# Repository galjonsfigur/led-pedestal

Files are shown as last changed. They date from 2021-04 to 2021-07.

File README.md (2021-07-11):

# LED Pedestal

This repository contains hardware, firmware and
3D-printable case for the LED Pedestal project.

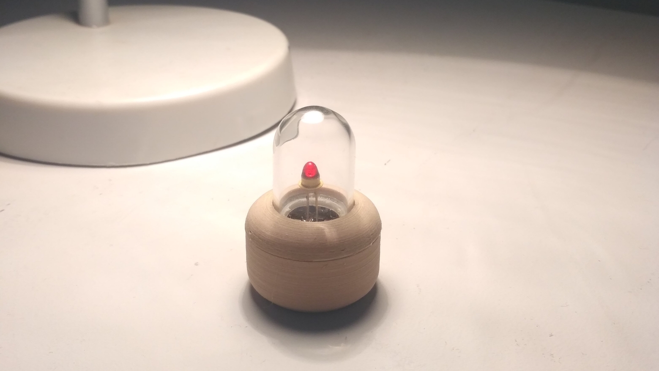
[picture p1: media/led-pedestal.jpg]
LED Pedestal


## What is this project?

The name says it all - it's just a fancy-looking circuit
that can blink your precious (retro or not) LED that you probably
still keep at the bottom of your component drawer. The circuit is heavily
over-complicated and the same thing could be done using 3 or 4 components total,
but it looks cool and has some nice features:

- PIC10F222 micro controller with sophisticated firmware (as far as 512 bytes 
firmware written in C with some assembly can be)
- Whole 3 (three!) randomly-parameterized LED effects to select from 
- Micro USB for charging the Li-Ion battery with all the (unnecessary)
protection circuits (overcharge, over-discharge and short-circuit protection) 
- small button for checking battery level and changing LED Blinking modes
- reaction to connecting charger and showing charging status
- can work while charging from USB

And on top of that, cool-looking glass dome case 
to encapsulate the spirit of your LED!

LED Pedestal

## How do I make my own?

Before you start you have to:

- be able to solder small SMD components (TSSOP-8 is the smallest-pitch used in
the design) and use hot-air or hot plate (or frying pan) to solder
micro USB port (you could try to use soldering iron but it will be much more 
tedious) 
- be able to program PIC10F222 micro controller (even cheap PICKit2 can be used)
- calculate current-limiting resistor for your LED assuming 3.3V drive voltage,
voltage drop and recommended current from LED datasheet. You can calculate it
using the following formula: `R = (V_battery - V_LEDdrop) / I_LED` or just slam
68 Ohm one and call it a day 

You can use available [gerber zip](hardware/gerbers_v2.zip) archive and order
the PCB from your favorite (or the cheapest) PCB manufacturer and buy the 
necessary components listed in the Bill of materials (most of them should be
cheap and easy to obtain even from places like AliExpress).

Bill of materials can be found [here.](bom.txt)

#### Assembly of the PCB

If you are soldering the PCB by hand, begin with USB port and the button 
Jumper from middle pad to pad marked with an arrow is variant with Random 
Seed Generator (Not implemented) and the jumper from middle pad to the 
third one (the one without arrow mark) is variant with battery 
measurement - connected by default in revision 2 of PCB, so if by any chance
you uploaded `gerbers_v1` instead of `gerbers_v2` you will have to solder it.
If your precious LED still has long legs don't cut them and instead solder it to
be as high above the PCB as possible! Cathode is the square pad. After soldering
SMD components solder trough-hole JST socket or the Li-ion cell directly.

If for whatever reason don't want to use 
[SOICBite](https://github.com/SimonMerrett/SOICbite) you can solder wires to the
pads directly and connect it to the programmer or program the PIC before
soldering it. Connection diagram can be found in the schematic and programming 
pads description in `media` folder). Example programming jig:

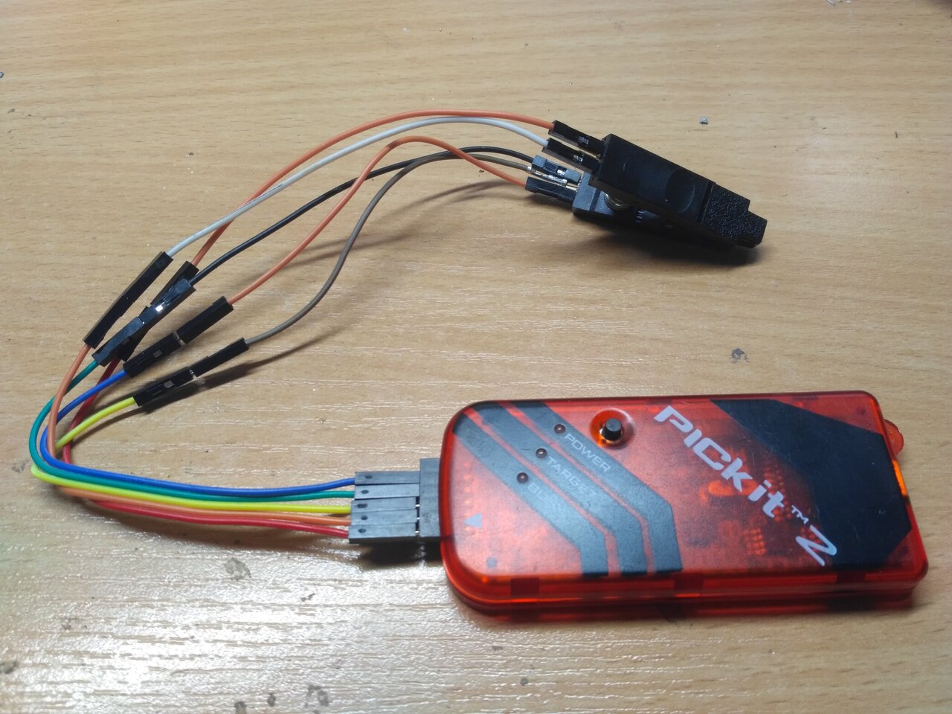
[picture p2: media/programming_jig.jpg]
Programming Jig


After connecting the Li-Ion cell you have to connect it to the USB
to start the protection circuits (they go to fail-save mode if the battery was
disconnected) and you should have a nice and working pedestal!

#### Assembling the case

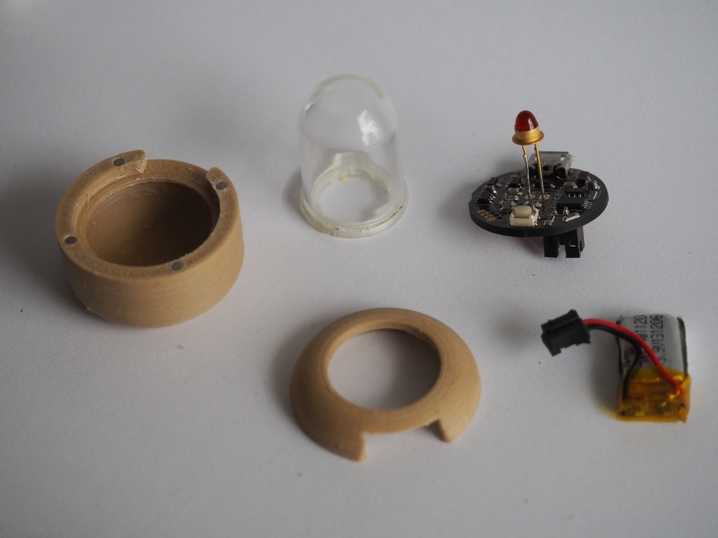
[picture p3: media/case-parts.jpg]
Case parts


To assemble the case you will need following elements:

- three 3D-printed parts - STL files are in `case` folder. I recommend to print
them with some nice material and fine settings - they should look better than
your average print!
- eight round 2x2mm N35 magnets
- 12x18mm glass dome

You should be able to get those on AliExpress or similar sites. 
Glue 3D-printed ring to the bottom of glass dome and put the magnets
into the holes in such configuration that two case parts attract each 
other. then put the PCB and the battery into the bottom part, the glass dome
into the upper one and they should snap together. 

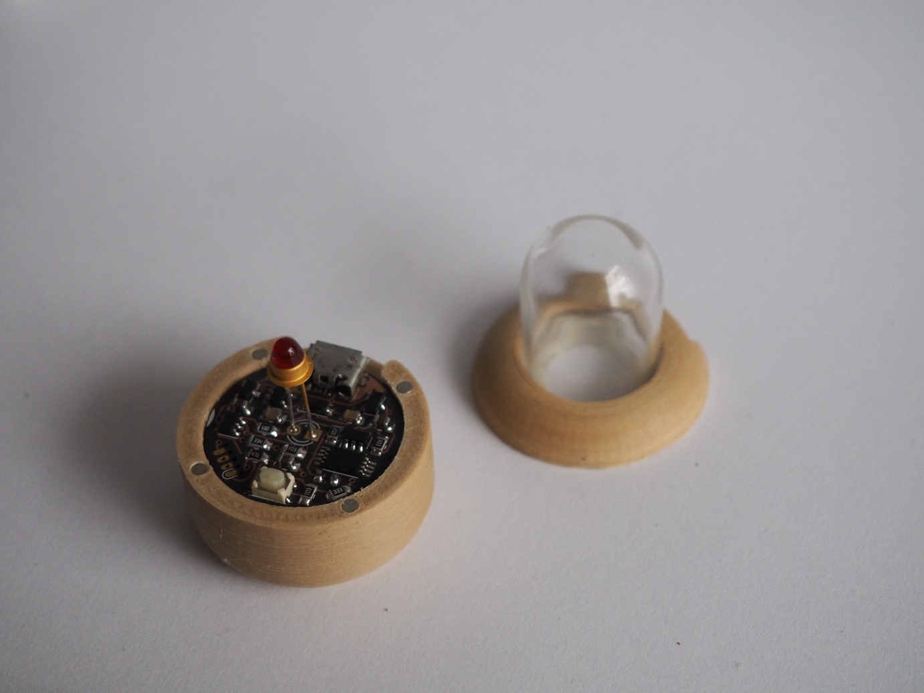
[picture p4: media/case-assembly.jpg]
Case


## Battery life
On 35mAh Li-ion 3.7V battery it should work:

- about 20 hours when in random blink mode
- about 15 hours when in both breathing modes
- much longer when in shutdown mode (PIC has to wake up every ~2 seconds just to
go to sleep again)

It mostly depends on the LED used as the firmware does everything it can
to preserve battery life.

## More pictures?

Gallery can be found in `media` folder if you like even more photos and videos
of this thingy.

## How do I use this?

If you click the button, the device will blink out it's status:

- if connected to charger
	- two short blinks means that it's charged
	- two slightly longer blinks means that its still charging
- if working from battery
	- from 6 to 2 blinks that indicate battery level - more blinks means more
	battery left
	- one short blink means battery is almost empty
	- no blinks means it's dead and you should connect it to USB

To change blinking mode, you have to press the button until LED will make a long
blink - that means it changed mode. If you don't release the button the 
mode will keep changing to next one on list bellow with each long blink. 

Implemented modes (whole four!):

- Random LED blink
- Sine-like LED breathing
- Linear LED breathing
- Power-off

### What else can/could be done:
The project is functional as-it-is but there is some room for improvements for
the software (hardware-wise it probably would be better to just connect it 
to Digispark and call it a day):

- Test other effects than RNG-BLINKENKIGHT, Quadwave and Triwave fading - simple
"test jig" can be found in `effects-workdir` folder.
- Try to rewrite current `quadwave` effect as it's not well suited 
for the PIC core
- Think of better effects that could be implemented given so little space

### Differences between PCB versions:

- change of some component values to reduce number of different resistor values
- more silkscreen markings on new PCB
- bigger pads on the button footprint (previous were hard to solder
  without hot plate) 
- the button is now closer to the PCB center - better fit with the case

## Author ramblings about the design

This whole project started because of the one small LED found in old lab
equipment and most of the decisions weren't really well-thought - after all
it wasn't meant to be some mass-produced product (if you want thing like that
you could just buy electronic candle) and, as always, only after the fact 
better ideas start popping in one's head. Bellow are some of them:

- Using other SOT-23 micro controller would probably allow for more effects and
slightly better battery life - for example PIC0F322 or Padauk PMS150C-U06 
or ATiny10, but I had access only to PIC10F222 so I used those. If someone would
want to port this firmware to other micro it should be possible - it's (almost)
C after all. I wanted to use SOT-23 as much as possible because it's small but
still fairly easy to solder, but there are many other options.
- Whole battery protection circuit could be ditched as even small Li-ion cell
come with one or at least change FS8205A to SOT-23 version that is smaller 
and easier to solder.
- Some elements around the button pin could be probably removed (they were there
because at design time it was undecided if this pedestal should work only 
on button press or the button would control the mode. Now those elements
function as over-complicated debouncing circuit. 
- author thought on the idea to make random seed generator based on
fluctuations of RC time constant where instead of resistor, a thermistor would
be used. But as it turned out, 16-bit LSFR was sufficient and showing battery
level seemed more useful in this useless device. If the capacitor will be
charged and pin function would be switched to ADC, the voltage level would
depend only on R value that is dependent on temperature. But on 8-bit fixed
sampling time ADC the variation wouldn't be too big(if any) so multiple readings
would be needed to extract any entropy from it.

## License
BSD 3-Clause

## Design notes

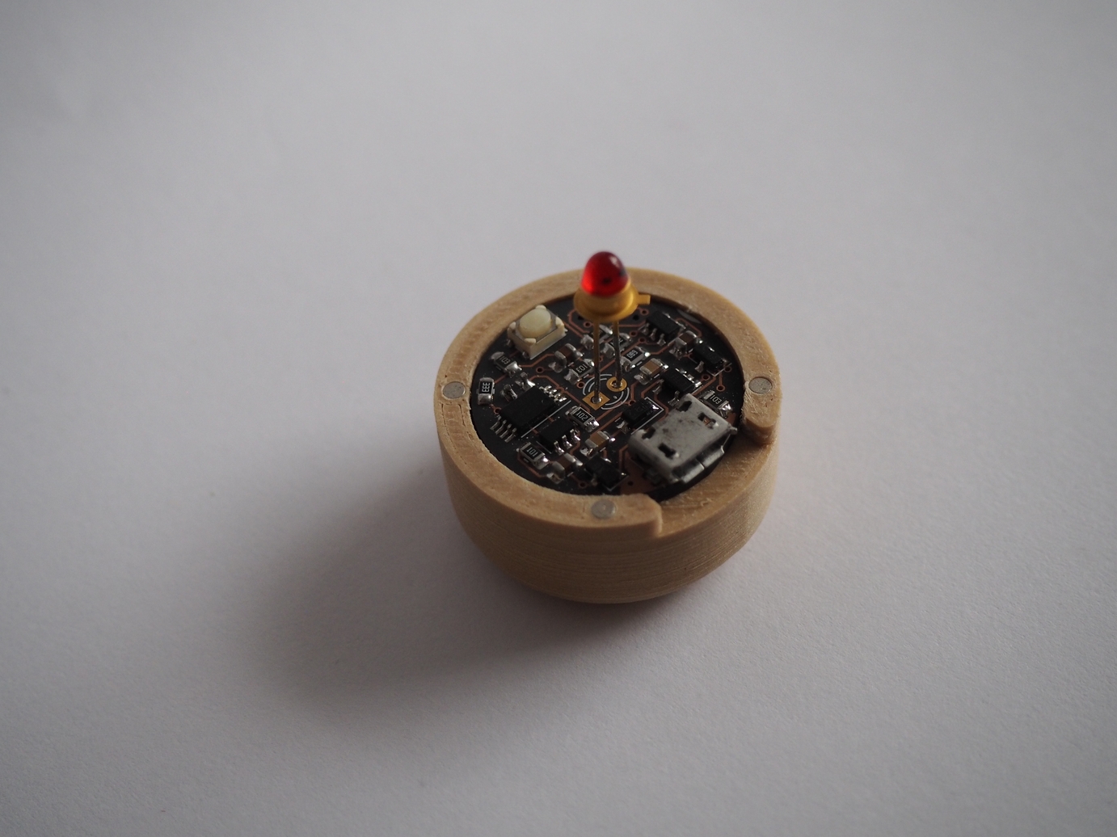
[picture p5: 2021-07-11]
media/inside-1.jpg

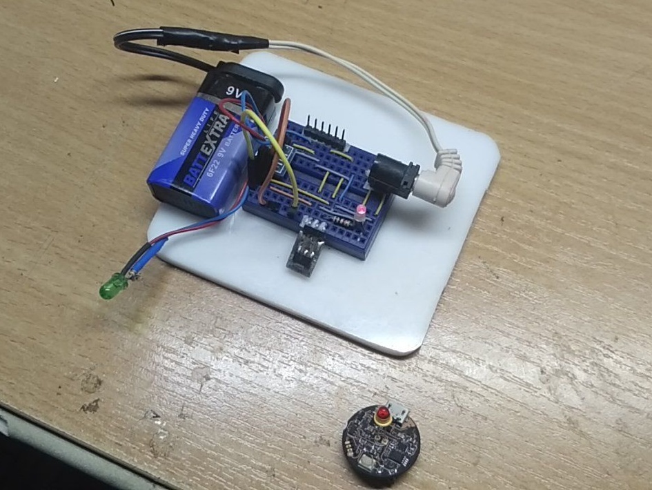
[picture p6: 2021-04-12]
media/prototype_and_rev1.jpg

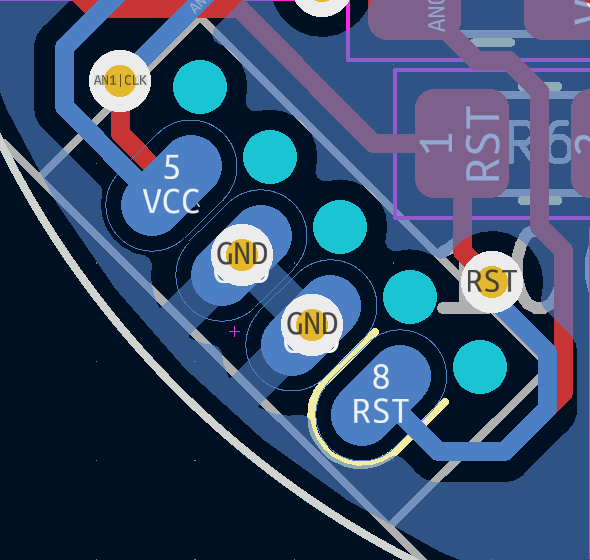
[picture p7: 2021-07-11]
media/bottom_layer.png

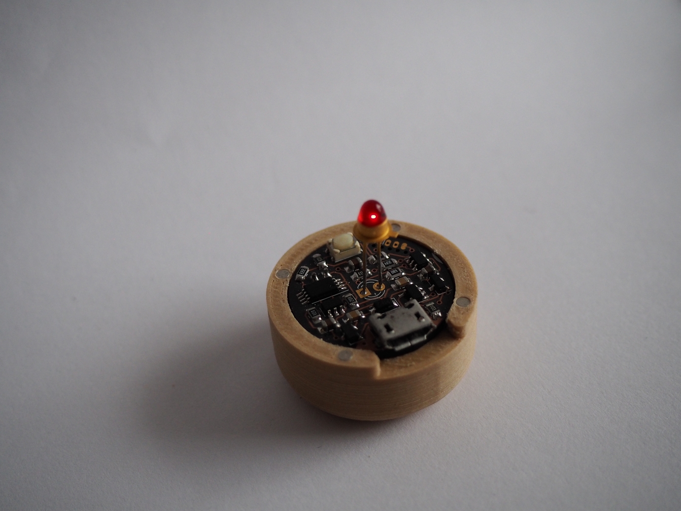
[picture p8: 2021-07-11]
media/inside-lights.jpg

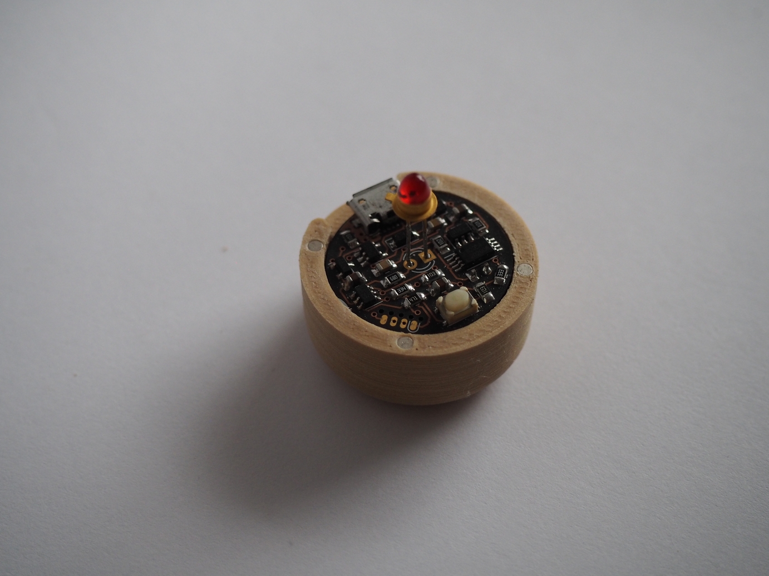
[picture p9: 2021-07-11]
media/inside-2.jpg

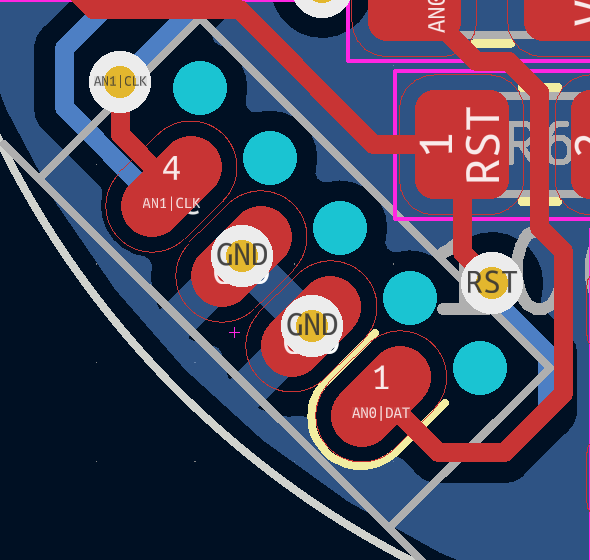
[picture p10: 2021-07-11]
media/top_layer.png

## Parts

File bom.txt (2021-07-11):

+--------------------+--------------------------+---------------------------------------------------------------+----------------------------------------------------------------------------------+
| Ref                | Value                    | Footprint                                                     | Datasheet                                                                        |
+--------------------+--------------------------+---------------------------------------------------------------+----------------------------------------------------------------------------------+
| BT1                | Li-Ion                   | Connector_JST:JST_PH_B2B-PH-K_1x02_P2.00mm_Vertical           | ~                                                                                |
+--------------------+--------------------------+---------------------------------------------------------------+----------------------------------------------------------------------------------+
| C1                 | 100nF                    | Capacitor_SMD:C_0805_2012Metric_Pad1.18x1.45mm_HandSolder     | ~                                                                                |
+--------------------+--------------------------+---------------------------------------------------------------+----------------------------------------------------------------------------------+
| C2                 | 1uF                      | Capacitor_SMD:C_0805_2012Metric_Pad1.18x1.45mm_HandSolder     | ~                                                                                |
+--------------------+--------------------------+---------------------------------------------------------------+----------------------------------------------------------------------------------+
| C4                 | 100nF                    | Capacitor_SMD:C_0805_2012Metric_Pad1.18x1.45mm_HandSolder     | ~                                                                                |
+--------------------+--------------------------+---------------------------------------------------------------+----------------------------------------------------------------------------------+
| C5                 | 100nF                    | Capacitor_SMD:C_0805_2012Metric_Pad1.18x1.45mm_HandSolder     | ~                                                                                |
+--------------------+--------------------------+---------------------------------------------------------------+----------------------------------------------------------------------------------+
| C6                 | 1uF                      | Capacitor_SMD:C_0805_2012Metric_Pad1.18x1.45mm_HandSolder     | ~                                                                                |
+--------------------+--------------------------+---------------------------------------------------------------+----------------------------------------------------------------------------------+
| D1                 | MBR0520                  | Diode_SMD:D_SOD-123                                           | http://www.mccsemi.com/up_pdf/MBR0520~MBR0580(SOD123).pdf                        |
+--------------------+--------------------------+---------------------------------------------------------------+----------------------------------------------------------------------------------+
| D2                 | RETRO LED                | LED_THT:LED_D3.0mm_FlatTop                                    | ~                                                                                |
+--------------------+--------------------------+---------------------------------------------------------------+----------------------------------------------------------------------------------+
| J1                 | USB_B_Micro              | Connector_USB:USB_Micro-B_Molex_47346-0001                    | ~                                                                                |
+--------------------+--------------------------+---------------------------------------------------------------+----------------------------------------------------------------------------------+
| Q1                 | AO3401A                  | Package_TO_SOT_SMD:SOT-23                                     | http://www.aosmd.com/pdfs/datasheet/AO3401A.pdf                                  |
+--------------------+--------------------------+---------------------------------------------------------------+----------------------------------------------------------------------------------+
| R1                 | 33k                      | Resistor_SMD:R_0805_2012Metric_Pad1.20x1.40mm_HandSolder      | ~                                                                                |
+--------------------+--------------------------+---------------------------------------------------------------+----------------------------------------------------------------------------------+
| R2                 | 100                      | Resistor_SMD:R_0805_2012Metric_Pad1.20x1.40mm_HandSolder      | ~                                                                                |
+--------------------+--------------------------+---------------------------------------------------------------+----------------------------------------------------------------------------------+
| R3                 | 1k                       | Resistor_SMD:R_0805_2012Metric_Pad1.20x1.40mm_HandSolder      | ~                                                                                |
+--------------------+--------------------------+---------------------------------------------------------------+----------------------------------------------------------------------------------+
| R4                 | 330k                     | Resistor_SMD:R_0805_2012Metric_Pad1.20x1.40mm_HandSolder      | ~                                                                                |
+--------------------+--------------------------+---------------------------------------------------------------+----------------------------------------------------------------------------------+
| R5                 | 68                       | Resistor_SMD:R_0805_2012Metric_Pad1.20x1.40mm_HandSolder      | ~                                                                                |
+--------------------+--------------------------+---------------------------------------------------------------+----------------------------------------------------------------------------------+
| R6                 | 100                      | Resistor_SMD:R_0805_2012Metric_Pad1.20x1.40mm_HandSolder      | ~                                                                                |
+--------------------+--------------------------+---------------------------------------------------------------+----------------------------------------------------------------------------------+
| R7                 | 10k                      | Resistor_SMD:R_0805_2012Metric_Pad1.20x1.40mm_HandSolder      | ~                                                                                |
+--------------------+--------------------------+---------------------------------------------------------------+----------------------------------------------------------------------------------+
| R8                 | 33k                      | Resistor_SMD:R_0805_2012Metric_Pad1.20x1.40mm_HandSolder      | ~                                                                                |
+--------------------+--------------------------+---------------------------------------------------------------+----------------------------------------------------------------------------------+
| R9                 | 10k                      | Resistor_SMD:R_0805_2012Metric_Pad1.20x1.40mm_HandSolder      | ~                                                                                |
+--------------------+--------------------------+---------------------------------------------------------------+----------------------------------------------------------------------------------+
| SW1                | SKRPACE010               | custom-symbols:SKRPACE010                                     | ~                                                                                |
+--------------------+--------------------------+---------------------------------------------------------------+----------------------------------------------------------------------------------+
| U1                 | LTC4054|TP4054           | Package_TO_SOT_SMD:TSOT-23-5                                  | https://www.analog.com/media/en/technical-documentation/data-sheets/405442xf.pdf |
+--------------------+--------------------------+---------------------------------------------------------------+----------------------------------------------------------------------------------+
| U2                 | FS8205A                  | Package_SO:TSSOP-8_4.4x3mm_P0.65mm                            | https://www.ic-fortune.com/upload/Download/FS8205A-DS-17_EN.pdf                  |
+--------------------+--------------------------+---------------------------------------------------------------+----------------------------------------------------------------------------------+
| U3                 | FS312F-G                 | Package_TO_SOT_SMD:SOT-23-6                                   | https://www.ic-fortune.com/upload/Download/FS312F-G-DS-12_EN.pdf                 |
+--------------------+--------------------------+---------------------------------------------------------------+----------------------------------------------------------------------------------+
| U4                 | XC6206P332MR             | Package_TO_SOT_SMD:SOT-23                                     | https://www.torexsemi.com/file/xc6206/XC6206.pdf                                 |
+--------------------+--------------------------+---------------------------------------------------------------+----------------------------------------------------------------------------------+
| U5                 | PIC10F222-IOT            | Package_TO_SOT_SMD:SOT-23-6                                   | http://ww1.microchip.com/downloads/en/DeviceDoc/41270E.pdf                       |
+--------------------+--------------------------+---------------------------------------------------------------+----------------------------------------------------------------------------------+
| Other components   |                          |                                                               |                                                                                  |
+--------------------+--------------------------+---------------------------------------------------------------+----------------------------------------------------------------------------------+
| Name               | Type                     | Notes                                                         | Links                                                                            |
+--------------------+--------------------------+---------------------------------------------------------------+----------------------------------------------------------------------------------+
| Battery            | 401215 3.7 Li-Ion        |                                                               |                                                                                  |
+--------------------+--------------------------+---------------------------------------------------------------+----------------------------------------------------------------------------------+
| Battery connector  | JST-PH 2.0 2 pin male    | Can be skipped if you don't plan to disconnect battery        |                                                                                  |
+--------------------+--------------------------+---------------------------------------------------------------+----------------------------------------------------------------------------------+
| Magnets            | 8x 2x2 round N35 magnets |                                                               | https://aliexpress.com/item/1005001408258171.html                                |
+--------------------+--------------------------+---------------------------------------------------------------+----------------------------------------------------------------------------------+
| Glass dome         | 18x25mm glass dome       |                                                               | https://aliexpress.com/item/32875328899.html                                     |
+--------------------+--------------------------+---------------------------------------------------------------+----------------------------------------------------------------------------------+
| Glass dome adapter | 3D printed part          | Best if printed with small nozzle size                        | File: glass_dome_adapter_v1.stl                                                  |
+--------------------+--------------------------+---------------------------------------------------------------+----------------------------------------------------------------------------------+
| Case base          | 3D printed part          | Best if printed with good quality settings and fancy filament | File: base_v2.stl                                                                |
+--------------------+--------------------------+---------------------------------------------------------------+----------------------------------------------------------------------------------+
| Case top           | 3D printed part          | Best if printed with good quality settings and fancy filament | File: top_v2.stl                                                                 |
+--------------------+--------------------------+---------------------------------------------------------------+----------------------------------------------------------------------------------+

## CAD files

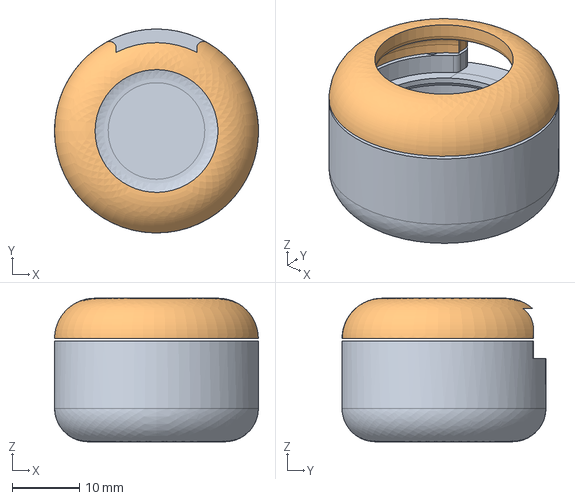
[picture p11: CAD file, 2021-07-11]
case/led-pedestal-case.FCStd
30.4 x 30.4 x 21.4 mm
Base

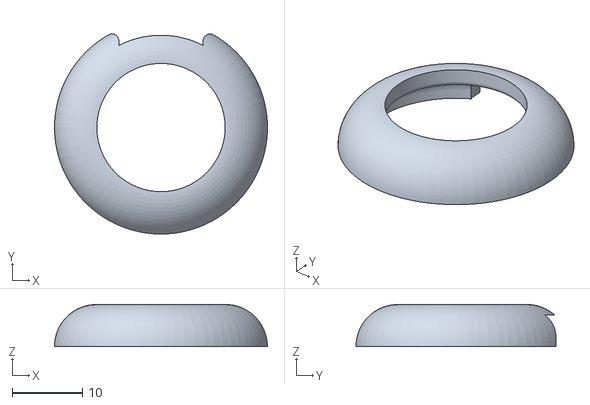
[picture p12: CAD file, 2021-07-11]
case/stl-files/top_v2.stl
30.4 x 28.6 x 6.00

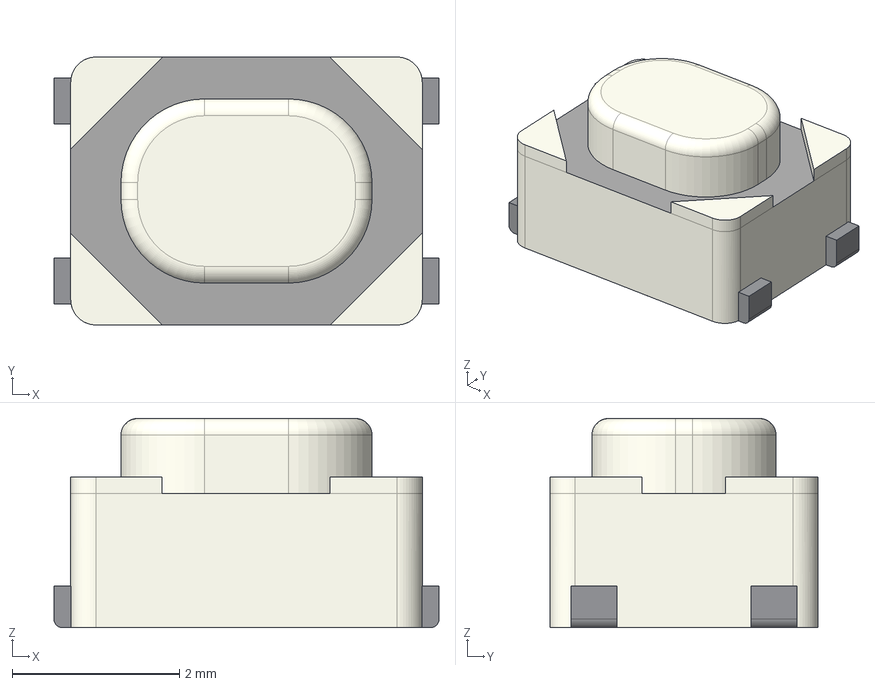
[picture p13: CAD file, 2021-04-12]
hardware/custom-symbols/SKRPACE010.step
4.60 x 3.20 x 2.50 mm

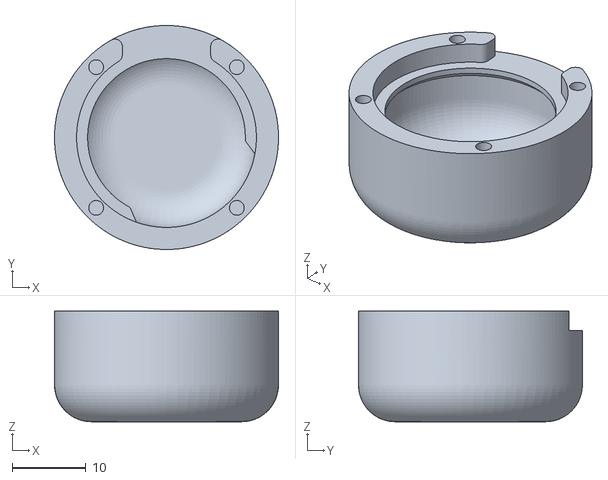
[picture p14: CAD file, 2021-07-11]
case/stl-files/base_v2.stl
30.4 x 30.4 x 15.0

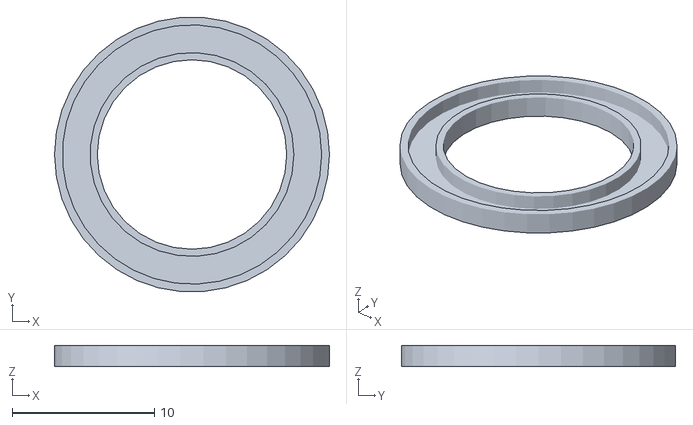
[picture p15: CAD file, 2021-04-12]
case/stl-files/glass_dome_adapter_v1.stl
19.3 x 19.2 x 1.50

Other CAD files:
case/stl-files/base_v1.stl
case/stl-files/top_v1.stl

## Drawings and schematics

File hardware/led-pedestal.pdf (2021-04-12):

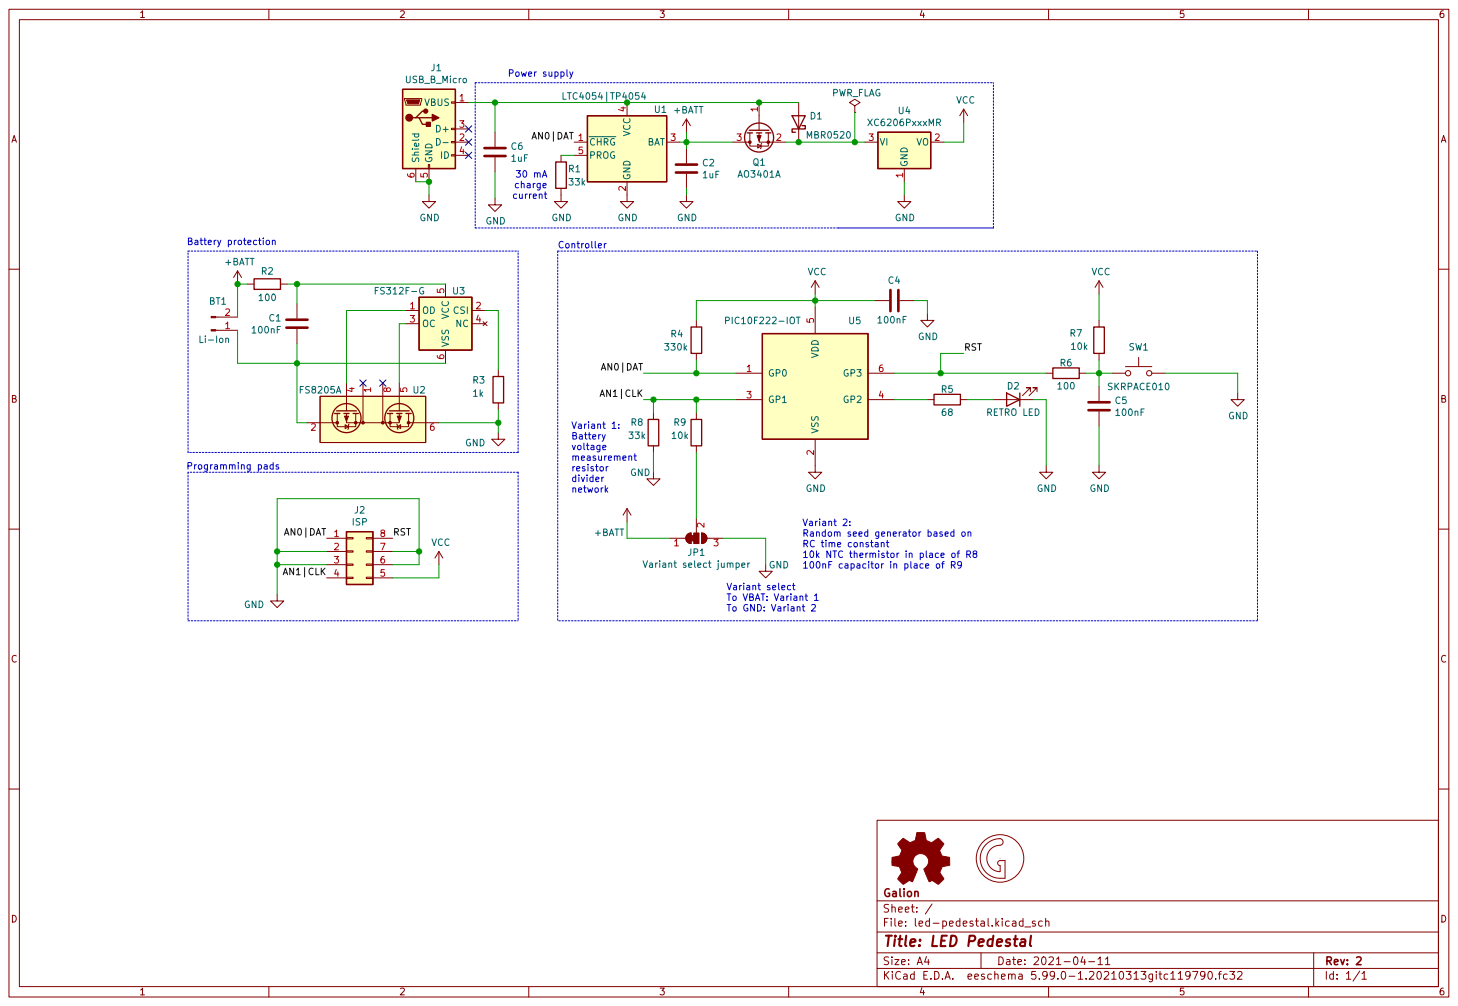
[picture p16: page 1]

voltage measurement resistor divider network

100nF capacitor in place of R9

File: led-pedestal.kicad_sch Sheet: / Galion

Id: 1/1 Title: LED Pedestal

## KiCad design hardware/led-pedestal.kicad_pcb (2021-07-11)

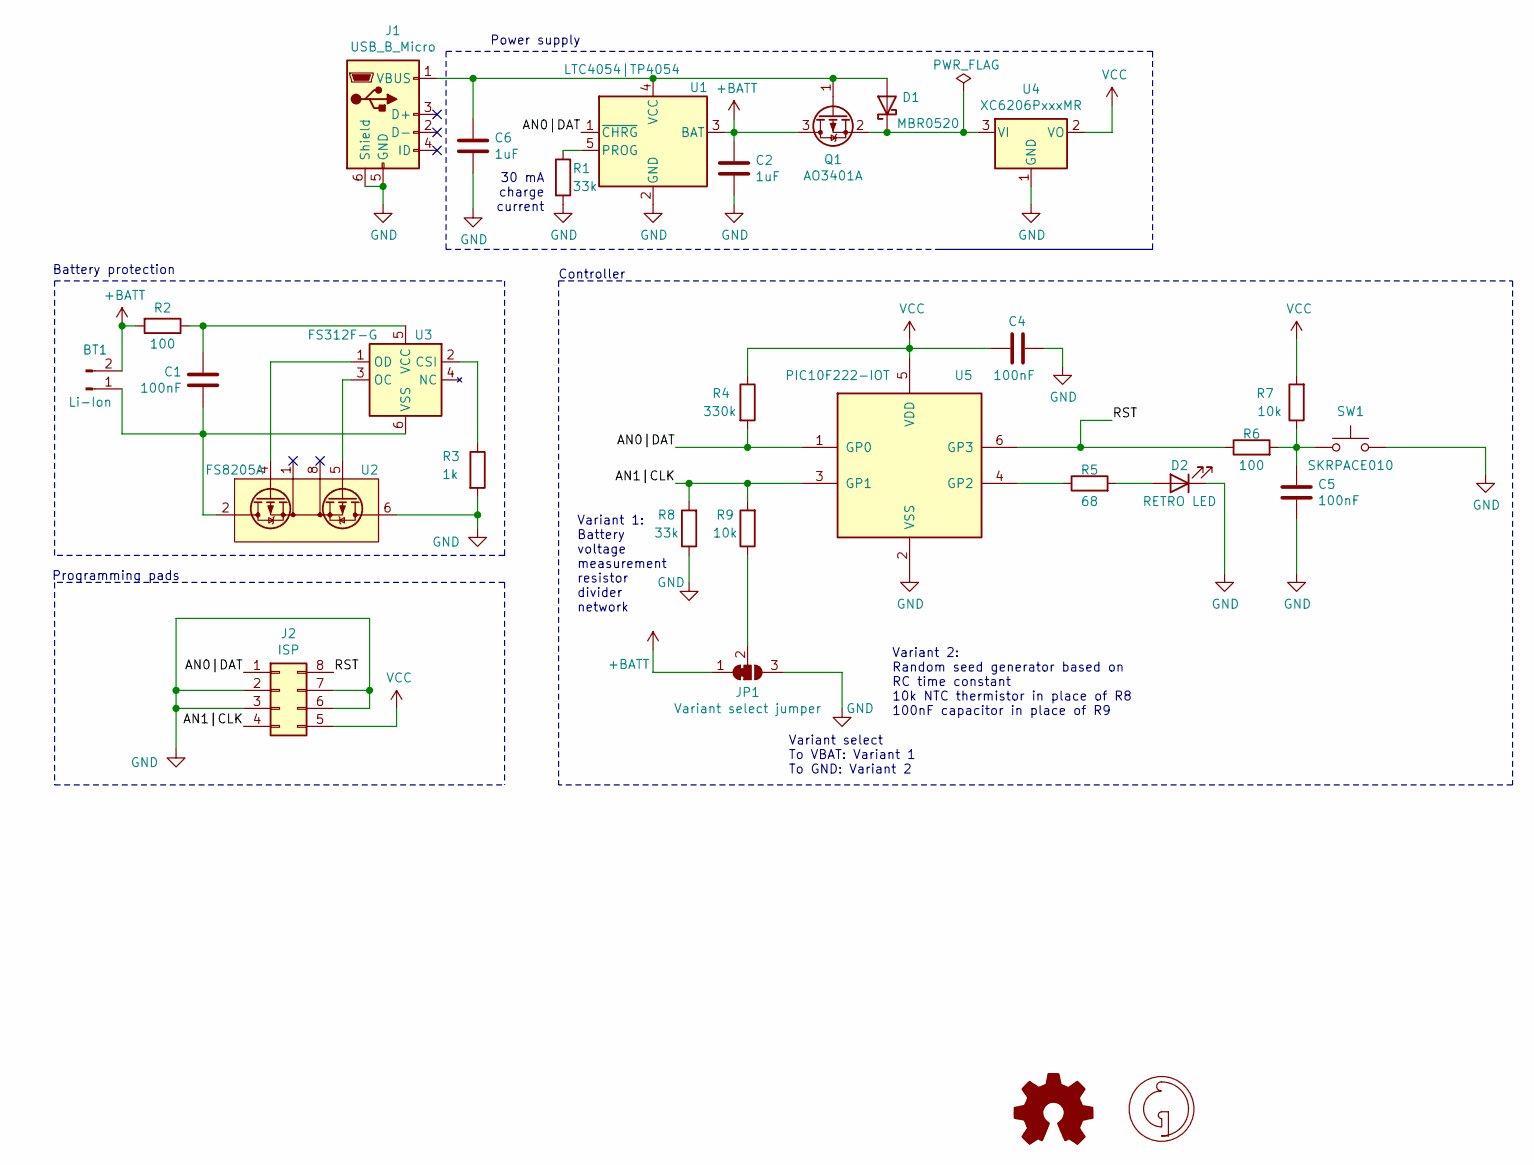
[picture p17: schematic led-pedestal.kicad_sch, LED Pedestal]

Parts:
BT1: Li-Ion; JST_PH_B2B-PH-K_1x02_P2.00mm_Vertical
C1, C4, C5: 100nF; C_0805_2012Metric_Pad1.18x1.45mm_HandSolder
C2, C6: 1uF; C_0805_2012Metric_Pad1.18x1.45mm_HandSolder
D1: MBR0520; D_SOD-123
D2: RETRO LED; LED_D3.0mm_FlatTop
J1: USB_B_Micro; USB_Micro-B_Molex_47346-0001
J2: ISP; SOIC_clipProgSmall
JP1: Variant select jumper; SolderJumper-3_P1.3mm_Bridged12_RoundedPad1.0x1.5mm_NumberL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
LG1: Galion_Logo; Galion_Logo_Small
LG2: Logo_Open_Hardware_Small; OSHW-Symbol_6.7x6mm_SilkScreen
Q1: AO3401A; SOT-23
R1, R8: 33k; R_0805_2012Metric_Pad1.20x1.40mm_HandSolder
R2, R6: 100; R_0805_2012Metric_Pad1.20x1.40mm_HandSolder
R3: 1k; R_0805_2012Metric_Pad1.20x1.40mm_HandSolder
R4: 330k; R_0805_2012Metric_Pad1.20x1.40mm_HandSolder
R5: 68; R_0805_2012Metric_Pad1.20x1.40mm_HandSolder
R7, R9: 10k; R_0805_2012Metric_Pad1.20x1.40mm_HandSolder
SW1: SKRPACE010
U1: LTC4054|TP4054; TSOT-23-5
U2: FS8205A; TSSOP-8_4.4x3mm_P0.65mm
U3: FS312F-G; SOT-23-6
U4: XC6206PxxxMR; SOT-23
U5: PIC10F222-IOT; SOT-23-6

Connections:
+BATT: BT1.2, C2.1, JP1.1 (A), Q1.3 (D), R2.2, U1.3 (BAT)
/AN0|DAT: J2.1, R4.2, U1.1 (~CHRG), U5.1 (GP0)
/AN1|CLK: J2.4, R8.2, R9.2, U5.3 (GP1)
/RST: J2.8, R6.1, U5.6 (GP3)
GND: C2.2, C4.2, C5.2, C6.2, D2.1 (K), J1.5 (GND), J1.6 (Shield), J2.2, J2.3, J2.6, J2.7, JP1.3 (B), R1.2, R3.2, R8.1, SW1.3, SW1.4, U1.2 (GND), U2.6 (S2), U2.7 (S2), U4.1 (GND), U5.2 (VSS)
unnamed: BT1.1, C1.2, U2.2 (S1), U2.3 (S1), U3.6 (VSS)
unnamed: C1.1, R2.1, U3.5 (VCC)
unnamed: C5.1, R6.2, R7.1, SW1.1, SW1.2
unnamed: C6.1, D1.2 (A), J1.1 (VBUS), Q1.1 (G), U1.4 (VCC)
unnamed: D1.1 (K), Q1.2 (S), U4.3 (VI)
unnamed: D2.2 (A), R5.2
unnamed: JP1.2 (C), R9.1
unnamed: R1.1, U1.5 (PROG)
unnamed: R3.1, U3.2 (CSI)
unnamed: R5.1, U5.4 (GP2)
unnamed: U2.4 (G1), U3.1 (OD)
unnamed: U2.5 (G2), U3.3 (OC)
VCC: C4.1, J2.5, R4.1, R7.2, U4.2 (VO), U5.5 (VDD)

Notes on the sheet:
Battery protection
Programming pads
30 mA charge current
Variant 1: Battery voltage measurement resistor divider network
Power supply
Controller
Variant select To VBAT: Variant 1 To GND: Variant 2
Variant 2: Random seed generator based on RC time constant 10k NTC thermistor in place of R8 100nF capacitor in place of R9

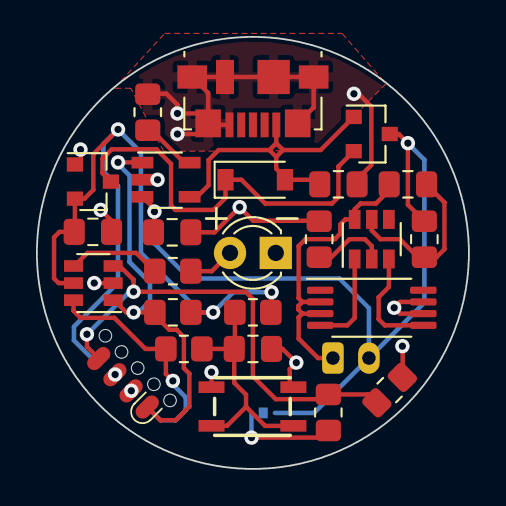
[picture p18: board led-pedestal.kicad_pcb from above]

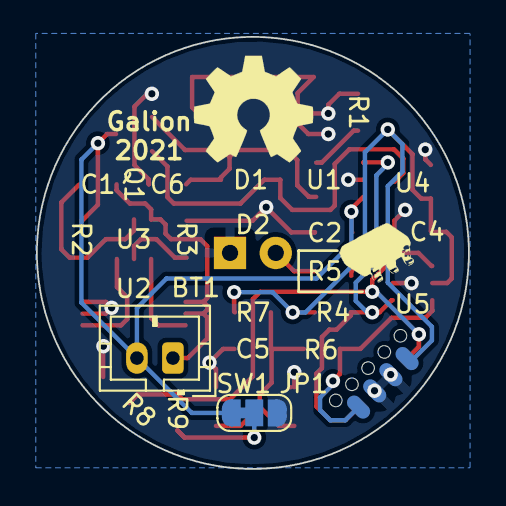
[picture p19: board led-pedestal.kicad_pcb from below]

Board: 2 copper layers, 24.0 x 24.0 mm, 29 parts (4 on the bottom side), 18 nets.

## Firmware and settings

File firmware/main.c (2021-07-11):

/* CONFIG */
#pragma config IOSCFS = 4MHZ    /* Internal Oscillator Frequency Select bit (4 MHz) */
#pragma config MCPU = OFF       /* Master Clear Pull-up Enable bit (Pull-up disabled) */
#pragma config WDTE = ON        /* Watchdog Timer Enable bit (WDT enabled) */
#pragma config CP = OFF         /* Code protection bit (Code protection off) */
#pragma config MCLRE = OFF      /* GP3/MCLR Pin Function Select bit (GP3/MCLR pin function is digital I/O, MCLR internally tied to VDD) */

#include <xc.h>
#include <stdint.h>

/*
 * Pin descriptions:
 *
 * GP0 - pin connected to CHRG pin on TP4054 to determine if the charger
 * is charging correctly or the battery itself is charged. Because TP4045 has 3
 * possible states, by using ADC and resistor those states can be detected.
 * When 3.3V is on it (logic high) that means the charger is not connected or
 * the battery is not charging (may be absent from circuit for example)
 * When around 0.5V is on the pin (still logic low because input is TTL) that
 * means the charging is complete
 * When 0V on the pin (logic low) that means TP4054 is charging the battery
 *
 * GP1 - pin connected to resistor divider network for the battery measurement
 * divider ratio is 76,75% (10k and 33k resistor) and it should always stay
 * above 2.3V if the battery is connected
 *
 * GP2 - LED output pin
 *
 * GP3 - button pin (active low) - when pressed the device should give it's
 * current battery/charging status. If pressed for longer it should change
 * current LED effect (3 available at the moment) or shutdown the device
 */

typedef union {
    uint8_t temp_8[2];
    uint16_t temp_16;
} scratch_ram_t;

typedef enum {
    BR_POWER_ON = 0x00,
    BR_PIN_CHANGE = 0x01,
    BR_WDT_WAKE_UP = 0x02,
    BR_RESET = 0x03
} bootreason_t;

/*
 * TODO: Simplify this logic maybe
 * States with even number are used when charger wasn't connected
 * After connecting charger, the device should show that it's charging on
 * connection moment - only once per charger connection. odd states will go
 * back to even when the charger is disconnected
 */
typedef enum {
    LEDMODE_RNGBLINK = 0x00,
    LEDMODE_RNGBLINK_BS = 0x01,
    LEDMODE_QUADWAVE = 0x02,
    LEDMODE_QUADWAVE_BS = 0x03,
    LEDMODE_TRIWAVE = 0x04,
    LEDMODE_TRIWAVE_BS = 0x05,
    LEDMODE_SHUTDOWN = 0x06,
    LEDMODE_SHUTDOWN_BS = 0x07,
} ledmode_t;

/* Prescaler selection for more random sine/triwave options */
const uint8_t prescaler_lut[4] = {0x03, 0x04, 0x05, 0x03};

 /* Used solely for keeping random numbers */
uint16_t random_16 = 0x9532;
/* Used for iterators in functions */
uint8_t i = 0;
/* GPIO status pins to write to when going to sleep  */
/* and read when wake-up on pin change occurred or ADC result */
__persistent uint8_t gpio_reg = 0;
/* Used as temporary value for things like RNG and blink routines */
scratch_ram_t scratch = {.temp_16 = 0};
/* Mode of the LED */
__persistent  ledmode_t mode = 0;

/* Function prototypes */
void get_next_random_16(void);
bootreason_t get_bootreason(void);
uint8_t triwave8(uint8_t in);
uint8_t quadwave8(uint8_t in);
void initIO(void);
void delay_32_ms(void);
void delay_tmr(uint8_t tmr_cycles);
void blink(uint8_t time_multiplier);
void show_charging_status(void);
void show_battery_status(void);
void change_mode_state(void);
void set_random_prescaler(void);

/* Functions */

/*
 * 16-bit Implementations of Galois LFSR (Linear Feedback Shift Register)
 * original source: http://www.piclist.com/techref/microchip/rand8bit.htm
 * original author: Mark Jeronimus
 * C equivalent function:
 * uint16_t random_16 = 1;
 * void next_rand_16() {
 *   uint8_t result = 1 & (random_16 >> 1);
 *   random_16 = random_16 >> 1;
 *   if (result == 0) {
 *     random_16 = random_16 ^ 0xA1A1;
 *   }
 * }
 */
void get_next_random_16() {
    __asm("clrw");
    __asm("bcf STATUS, 0"); /* Clear carry bit */
    __asm("rrf _random_16+1, 1"); /* Shift high part right through carry */
    __asm("rrf _random_16, 1"); /* Shift lwo part right through carry */
    __asm("btfss STATUS, 0"); /* Check carry bit */
    __asm("goto end_random"); /* if carry is 0 then end function */
    __asm("movlw 0xA1"); /* set W to A1 (0xA1A1 is polynomial value) */
    __asm("xorwf _random_16+1"); /* XOR 0xA1 with high part */
    __asm("xorwf _random_16"); /* XOR 0xA1 with low part */
    __asm("end_random:"); /* end of function */
}

bootreason_t get_bootreason() {
    if (STATUSbits.GPWUF == 1) {
        return BR_PIN_CHANGE; /* Pin change when in Sleep */
    } else if (__timeout == 0) {
        return BR_WDT_WAKE_UP; /* Reset Caused By WDT wake-up from Sleep */
    } else if (__powerdown == 1) {
        return BR_POWER_ON; /* Reset Caused By Power-up */
    } else return BR_RESET; /* Reset caused by MCLR reset */
}
/*
 * Slightly modified and inlined functions from lib8tion (FastLED Project)
 *
 * The MIT License (MIT)
 *
 * Copyright (c) 2013 FastLED
 *
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
of this software and associated documentation files (the "Software"), to deal
 * in the Software without restriction, including without limitation the rights
 * to use, copy, modify, merge, publish, distribute, sublicense, and/or sell
 * copies of the Software, and to permit persons to whom the Software is
 * furnished to do so, subject to the following conditions:
 *
 * The above copyright notice and this permission notice shall be included in
 * all copies or substantial portions of the Software.
 *
 * THE SOFTWARE IS PROVIDED "AS IS", WITHOUT WARRANTY OF ANY KIND, EXPRESS OR
 * IMPLIED, INCLUDING BUT NOT LIMITED TO THE WARRANTIES OF MERCHANTABILITY,
 * FITNESS FOR A PARTICULAR PURPOSE AND NONINFRINGEMENT. IN NO EVENT SHALL THE
 * AUTHORS OR COPYRIGHT HOLDERS BE LIABLE FOR ANY CLAIM, DAMAGES OR OTHER
 * LIABILITY, WHETHER IN AN ACTION OF CONTRACT, TORT OR OTHERWISE, ARISING
 * FROM, OUT OF OR IN CONNECTION WITH THE SOFTWARE OR THE USE OR OTHER DEALINGS
 * IN THE SOFTWARE.
 */

uint8_t triwave8(uint8_t in) {
    if( in & 0x80) {
        in = 255 - in;
    }
    uint8_t out = (uint8_t) (in << 1);
    return out;
}

uint8_t quadwave8(uint8_t in) {
    if( in & 0x80) {
        in = 255 - in;
    }
    uint8_t j = (uint8_t)(in << 1);
    if( j & 0x80 ) {
        j = 255 - j;
    }
    uint8_t jj  =  (((uint16_t) j) * (1+(uint16_t)(j))) >> 8;
    jj = (uint8_t)(jj << 1);
    if( in << 1 & 0x80 ) {
        jj = 255 - jj;
    }
    return jj;
}

/* Setup the IO to avoid strange LED glitches on power-up */
void initIO() {
    /* Enable wake-up on pin change, disable pull-ups, set prescaler */
    /* to 1:256 for Timer0 (1:128 for WDT) */
    OPTION = nGPPU | PS0 | PS1 | PS2;
    /* Select only GP2 as output and set it to low */
    GP2 = 0;
    TRISGPIO = 0x0B;
    /* Preconfigure ADC to use GP0 and GP1 but set them as digital pins */
    ADCON0 = 0x00;
}

/* Use timer to get ~32 ms delay on 4MHz oscillator and 1:256 prescaler */
void delay_32_ms() {
    TMR0 = 0;
    while(!(TMR0&0x80)) __asm("clrwdt");
}
/* Use timer to get a variable delay - useful for soft PWM */
void delay_tmr(uint8_t tmr_cycles) {
    TMR0 = 0;
    while (TMR0 != tmr_cycles);
}

void blink(uint8_t time) {
    GPIObits.GP2 = 1;
    blink_wait:
    for(scratch.temp_8[0] = time; scratch.temp_8[0] > 0; scratch.temp_8[0]--) {
        TMR0 = 0;
        while(!(TMR0&0x80)) __asm("clrwdt");
    }
    if (!GPIObits.GP2)
        return;
    GPIObits.GP2 = 0;
    goto blink_wait;
}

void show_charging_status() {
    /* Connect GP0 to ADC and communicate charging status to the user */
    /* by blinking: 2 short means charged and 2 long means charging */
    ADCON0bits.ANS0 = 1;
    ADCON0bits.CHS0 = 0;
    ADCON0bits.ADON = 1;
    /* Start conversion and wait for the result */
    ADCON0bits.GO = 1;
    while (ADCON0bits.nDONE);
    if (ADRES > 20) {
            blink(25);
            blink(25);
    } else {
            blink(15);
            blink(15);
    }
    /* Turn off ADC and disconnect the pin */
    ADCON0bits.ADON = 0;
    ADCON0bits.ANS0 = 0;
}

void show_battery_status() {
    /* Connect GP1 to ADC and communicate battery level */
    /* to the user by blinking the more the higher battery level */
    ADCON0bits.CHS0 = 1;
    ADCON0bits.ANS1 = 1;
    ADCON0bits.ADON = 1;
    /* Start conversion and wait for the result */
    ADCON0bits.GO = 1;
    while (ADCON0bits.nDONE);
    /* Sanity check - if battery is not present or */
    /* bellow 2.65V  make one quick blink */
    if (ADRES < 155) {
        blink(5);
    } else {
        /* Convert ADC result to amount of blinks */
        i = 1;
        if (ADRES > 200) i = 2;
        if (ADRES > 211) i = 3;
        if (ADRES > 219) i = 4;
        if (ADRES > 222) i = 5;
        if (ADRES > 229) i = 6;
        for (; i > 0; i--) {
            blink(10);
        }
    }

    /* Turn off ADC */
    ADCON0bits.ADON = 0;
    ADCON0bits.ANS1 = 0;
}

/* Changing of the mode will be happening as long as the button is pressed */
void change_mode_state() {
    while (!GPIObits.GP3) {
        /* Show demo of the function and if still pressed go to the next one */
        blink(60);
        if (mode < LEDMODE_SHUTDOWN) mode = mode + 2;
        else if (mode == LEDMODE_QUADWAVE_BS) mode = LEDMODE_SHUTDOWN_BS;
        else mode = LEDMODE_RNGBLINK;
    }
}

void set_random_prescaler() {
    OPTION = nGPPU | prescaler_lut[(uint8_t) (random_16 & 0x03)];
}

void main(void) {
    /* Some sanity checks to make sure the device will operate properly */
    if (mode > LEDMODE_SHUTDOWN_BS) mode = LEDMODE_RNGBLINK;
    /* Init random generator from given seed or the last value before sleep */
    if (scratch.temp_16 != 0) random_16 = scratch.temp_16;

    /* Init IO pins to default state */
    initIO();
    /* Check why device started */
    switch (get_bootreason()) {
        case BR_RESET:
        case BR_POWER_ON: {
            /* Wait for around 2 seconds before beginning power-up sequence */
            /* XXX: not working in simulator - probably a bug in MPLAB X 5.40 */
            for (i = 60; i > 0; i--) delay_32_ms();

            /* Check if charger is connected */
            if (!GPIObits.GP0) {
                /* If it is show charging status */
                show_charging_status();
                /* Go to odd state as charging was already shown */
                mode++;
            } else {
                /* If charger not connected display battery charge */
                show_battery_status();
            }
            /* Check if button is still pressed and change the mode if it is */
            change_mode_state();
            break;
        }
        case BR_PIN_CHANGE: {
            /* XOR old and new bit status and then AND it with mask */
            /* to get if the button caused the wake-up or was it  */
            /* battery or charger pin */
            gpio_reg = (gpio_reg ^ GPIO);

            if (gpio_reg & 0x08) {
                /* Button pressed - show battery/charging status */
                if (!GPIObits.GP0) {
                    show_charging_status();
                } else {
                    show_battery_status();
                }
                /* if still pressed change mode */
                change_mode_state();
            /* Charger connected/disconnected */
            } else if (gpio_reg & 0x01) {
                show_charging_status();
            } else {
                show_battery_status();
            }
            break;
        }
        case BR_WDT_WAKE_UP: {
            /* Do nothing and proceed */
        }
    }
    /* Skip this iteration once in a while */
    /* this is added because maximum WDT period of 2.3 seconds is too short */
    if (random_16 & 0x01) {
        i = nGPPU | PSA | PS0 | PS1 | PS2;
        goto set_wdt_and_sleep;
    }
    /* Show LED effect  */
    /* Set timer prescaler for random effect duration (only rngblink) */
    /* will use the longest because shorter blinks don't look that nice */
    set_random_prescaler();
    
    for (i = 255; i > 0; i--) {
        __asm("clrwdt"); /* Remember about watchdog */
        get_next_random_16();

        switch (mode) {
            case LEDMODE_RNGBLINK:
            case LEDMODE_RNGBLINK_BS: {
                /* The longest prescaler has to be used for this effect */
                OPTION = nGPPU | PS0 | PS1 | PS2;
                delay_32_ms();
                delay_32_ms();
                if (random_16 & 0x07) GPIObits.GP2 = 0;
                else                  GPIObits.GP2 = 1;
                break;
            }
            case LEDMODE_QUADWAVE:
            case LEDMODE_QUADWAVE_BS: {
                scratch.temp_8[0] = quadwave8(i);
                GPIObits.GP2 = 1;
                delay_tmr(scratch.temp_8[0]);
                GPIObits.GP2 = 0;
                delay_tmr(255-scratch.temp_8[0]);
                break;
            }
            case LEDMODE_TRIWAVE:
            case LEDMODE_TRIWAVE_BS: {
                scratch.temp_8[0] = triwave8(i);
                GPIObits.GP2 = 1;
                delay_tmr(scratch.temp_8[0]);
                GPIObits.GP2 = 0;
                delay_tmr(255-scratch.temp_8[0]);
                break;
            }
            /* Device shutdown
             * (status LEDMODE_SHUTDOWN or LEDMODE_SHUTDOWN_BS) 
             */
            default:
                /* Set the prescaler to make WDT sleep as long as possible */
                /* because WDT cannot be disabled at runtime */
                i = nGPPU | PSA | PS0 | PS1 | PS2;
                goto set_wdt_and_sleep;
        }


        /* Check if button was pressed */
        
        if (!GPIObits.GP3) {
            /* Set the prescaler to default value before going into settings */
            OPTION = nGPPU | PS0 | PS1 | PS2;
            /* Assume that charging/battery status will always be shown */
            if (!GPIObits.GP0) {
                show_charging_status();
            } else {
                show_battery_status();
            }
            /* If the button is still pressed after that get to change mode */
            change_mode_state();
            /* Restore prescaler - won't be same as before but in the range */
            set_random_prescaler();
        }
        /* Check if charger was connected and charging was not shown yet */
        if (!GPIObits.GP0 && (mode & 0x01) == 0) {
            /* Set the prescaler to default value before showing status */
            OPTION = nGPPU | PS0 | PS1 | PS2;
            show_charging_status();
            mode++; /* Go to odd state - charging status already shown */
            /* Restart showing of the effect */
            i = 0;
            set_random_prescaler();
        }
        /* Check if charger was disconnected and the state is odd to be able */
        /* to show charging reaction after another connection */
        if (GPIObits.GP0 && (mode & 0x01) == 1) {
            mode--; /* Go back to even state */
        }
    }

    /* Save random variable for the next time */
    scratch.temp_16 = random_16;
    /* get the 2 random bits to set the prescaler */
    /* to be random from 1:16 to 1:128 - works fine */
    i = nGPPU | PSA | (0x03 & scratch.temp_8[0]) | PS2;
    /* turn off LED (it could still be on because of the rngblink mode) */
    GPIObits.GP2 = 0;
    set_wdt_and_sleep:
        /* Read the registers to make wake up on pin change work correctly */
        gpio_reg = GPIO;
        /* Give the prescaler to WDT, set it and go to sleep */
        __asm("clrwdt");
        TMR0 = 0;
        OPTION = i;
        __asm("sleep");                
}

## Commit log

2021-04-12 Add revision 2 of the hardware
    Changes include:
    - moved button to the center for better fit of the case
    - added silkscreen marks for + and minus of the LED
    - connect jumper to battery measurement variant
    - lower charging current (from 100 to 30 mA)
    [led-pedestal-B_Cu.gbl, led-pedestal-B_Mask.gbs, led-pedestal-B_Silkscreen.gbo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]
2021-07-11 Re-export correct files for revision 2 of the PCB
    [led-pedestal-B_Cu.gbl, led-pedestal-B_Mask.gbs, led-pedestal-B_Silkscreen.gbo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]
2021-07-11 Add case files with holes for magnets
    [base_v2.stl, led-pedestal-case.FCStd, top_v2.stl]
2021-07-11 Squeeze some bytes to get more gradual battery levels to show
